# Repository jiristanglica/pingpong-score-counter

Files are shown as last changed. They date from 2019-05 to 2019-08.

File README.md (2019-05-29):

# Pingpong Score Counter

Pingpong score counter for our office pingis table.

## Architecture
Basic architecture consist of two Arduino Nano V3s that communicate wirelessly. There is a _buttons module_ and a _display module_. All parts are mounted in 3D printed enclosures. The .stl files for 3D printed parts are inside the `./assembly` folder in this repository.

### Buttons module
Buttons are mounted on each side of the table. Each button is connected into an Arduino Nano V3, which is mounted under the table.

**Components list**:
- 1x [Arduino Nano V3](https://store.arduino.cc/arduino-nano)
- 1x [NRF24L01+ module](https://www.elektroniikkaosat.com/c-45/p-464288850/NRF24L01-lahetin-vastaanotin.html)
- 1x [NRF24L01+ 5V adapter](https://www.elektroniikkaosat.com/c-45/p-529542940/NRF24L01-adapteri.html)
- 2x [Arcade Push Button](https://www.partco.fi/en/electromechanics/switches/arcade-switches/19574-kyt-arc33-sin.html)
- 2x 10kΩ resistor

Fritzing diagram showing the wiring:
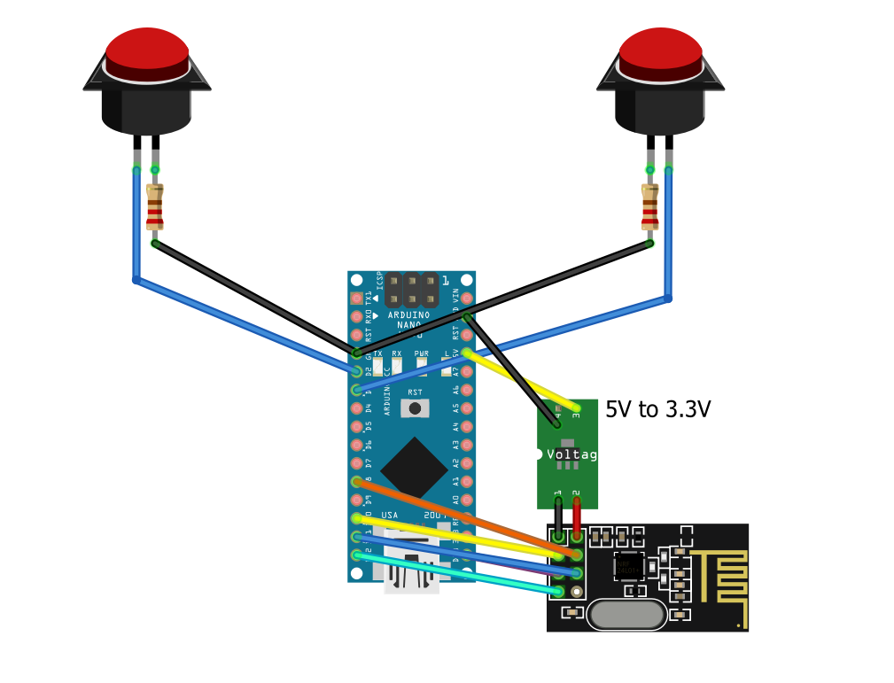
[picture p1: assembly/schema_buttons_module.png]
Buttons module schema


### Display module
Display is in a separate enclosure which can be placed on any suitable place within the reach of the 2.4GHz radio communication (and eyes of the players).

**Components list**:
- 1x [Arduino Nano V3](https://store.arduino.cc/arduino-nano)
- 1x [NRF24L01+ module](https://www.elektroniikkaosat.com/c-45/p-464288850/NRF24L01-lahetin-vastaanotin.html)
- 1x [NRF24L01+ 5V adapter](https://www.elektroniikkaosat.com/c-45/p-529542940/NRF24L01-adapteri.html)
- 1x [MAX7219 8x8x4 LED Matrix Module](https://www.partco.fi/en/arduino/arduino-playground/19683-max7219-mod-8x8x4.html)
- 1x [LK Buzzer](https://www.partco.fi/en/diy-kits/linkerkit/19405-lk-buzzer.html)

Fritzing diagram showing the wiring:
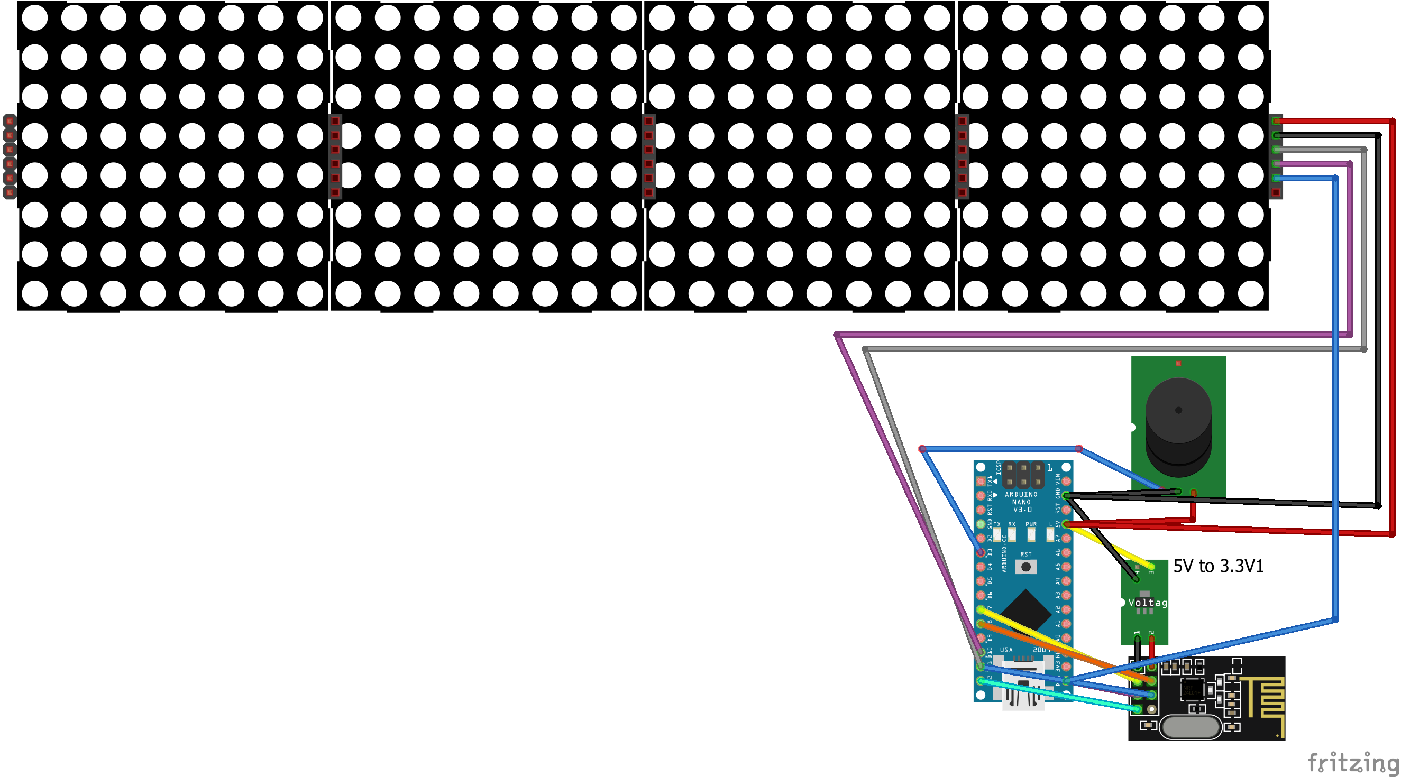
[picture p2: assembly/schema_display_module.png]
Buttons module schema


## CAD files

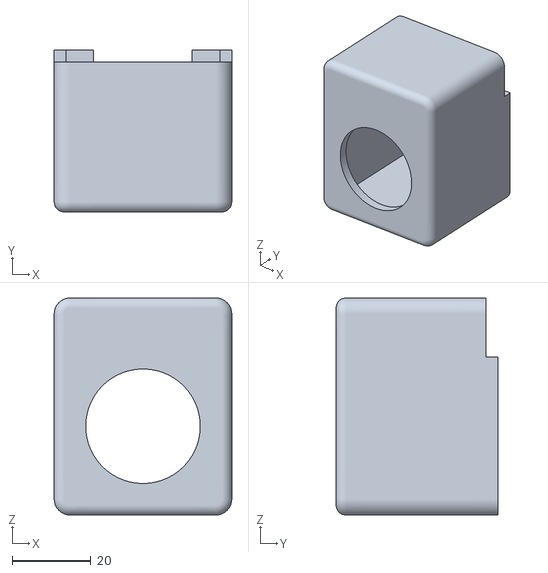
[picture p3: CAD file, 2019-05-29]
assembly/button_enclosure.stl
45.0 x 41.0 x 55.0

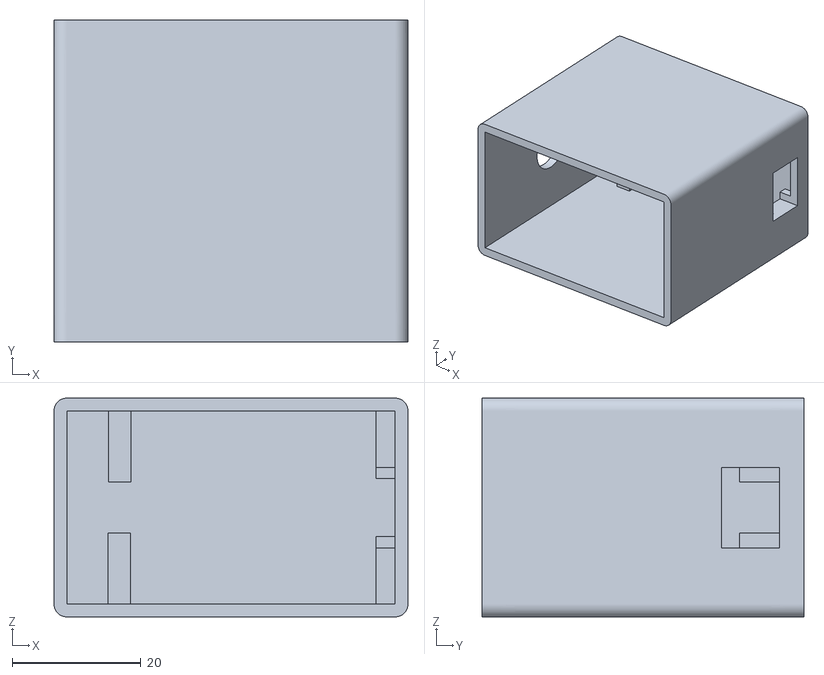
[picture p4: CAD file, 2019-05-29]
assembly/buttons_module_enclosure.stl
55.0 x 50.0 x 34.0

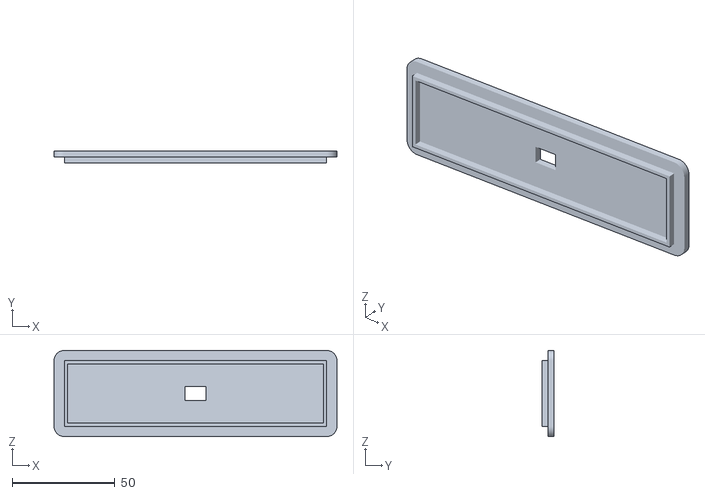
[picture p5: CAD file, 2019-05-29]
assembly/display_enclosure.stl
138.0 x 6.00 x 42.0

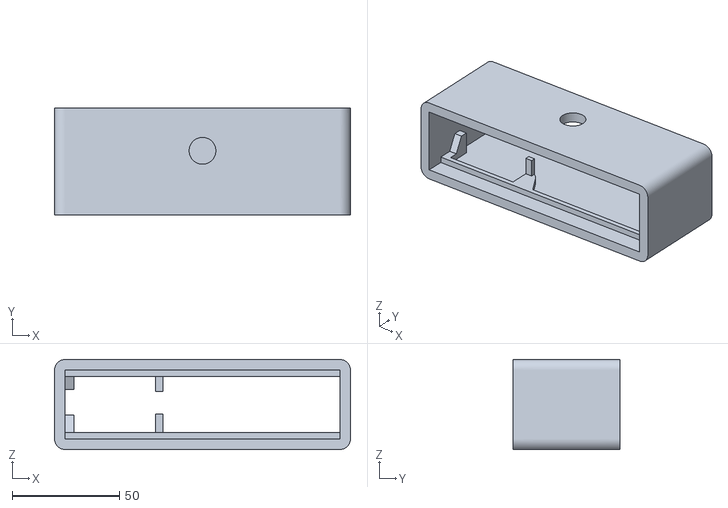
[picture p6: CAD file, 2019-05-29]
assembly/display_enclosure_lid.stl
138.0 x 50.0 x 42.0

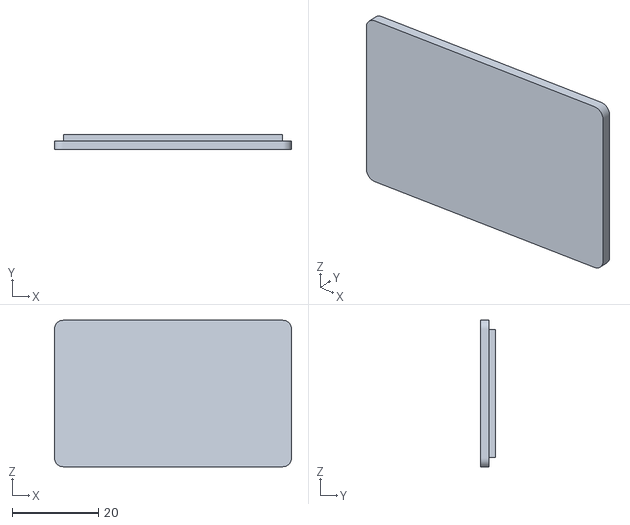
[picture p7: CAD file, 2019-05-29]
assembly/buttons_module_enclosure_lid.stl
55.0 x 3.50 x 34.0

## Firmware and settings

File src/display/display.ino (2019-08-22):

#include <nRF24L01.h>
#include <RF24.h>
#include <SPI.h>
#include "src/Display.h"
#include "src/Buzzer.h"

// Button 1 messages
#define RADIO_MSG_BUTTON_1_PRESS 0
#define RADIO_MSG_BUTTON_1_LONG_PRESS_1_SIGNAL 1
#define RADIO_MSG_BUTTON_1_LONG_PRESS_2_SIGNAL 2
#define RADIO_MSG_BUTTON_1_LONG_PRESS_1 3
#define RADIO_MSG_BUTTON_1_LONG_PRESS_2 4
// Button 2 messages
#define RADIO_MSG_BUTTON_2_PRESS 5
#define RADIO_MSG_BUTTON_2_LONG_PRESS_1_SIGNAL 6
#define RADIO_MSG_BUTTON_2_LONG_PRESS_2_SIGNAL 7
#define RADIO_MSG_BUTTON_2_LONG_PRESS_1 8
#define RADIO_MSG_BUTTON_2_LONG_PRESS_2 9

#define RADIO_MSG_HEARTBEAT 10

/** Buzzer variables */
Buzzer buzzer(3);

/** Radio varaibles */
RF24 radio(7, 8); // CE, CSN
const byte address[6] = "dsp001";
unsigned long lastHb = 0;
bool txLost = false;

/** Display variables */
Display disp = Display(4);

/** Display messages */
const char msgNewGame[] =    " New Game       ";  // 1
const char msgPlayer1Won[] = " Player 1 wins! ";  // 2
const char msgPlayer2Won[] = " Player 2 wins! ";  // 3
/** Display messages helper variables */
bool isTextScrolling = false;
unsigned long textScrollingTimer = 0;
byte msgDisplayed = 1;

/** Players variables */
typedef struct Players {
    int id;
    int score = 0;
    bool isServing = false;

    String scoreString() {
        char cstr[3]; // 2 chars + null termination
        itoa(this->score, cstr, 10);
        return cstr;
    }
    char scoreChar1() {
        String str = this->scoreString();
        if (str[1]) {
            return str[0];
        }
        return '0';
    }
    char scoreChar2() {
        String str = this->scoreString();
        if (str[1]) {
            return str[1];
        }
        return str[0];
    }
    void renderScore() {
        int renderOffset = 0;
        if (this->id == 2) {
            renderOffset = 19;
        }
        disp.printChar(this->scoreChar1(), renderOffset + 1);
        disp.printChar(this->scoreChar2(), renderOffset + 7);
        disp.setLed(7, renderOffset + 5, this->isServing);
        disp.setLed(7, renderOffset + 6, this->isServing);
        disp.setLed(7, renderOffset + 7, this->isServing);
    }
} Player;
Player player1;
Player player2;

/** Gameplay variables */
bool isGameOver = false;
int firstPlayerToPass = -1;

void setup()
{
    Serial.begin(57600);
    
    // Setup display
    disp.init();
    
    // Setup radio
    radio.begin();
    radio.openReadingPipe(0, address);
    radio.setPALevel(RF24_PA_MIN);
    radio.startListening();
    
    // Setup players
    player1.id = 1;
    player2.id = 2;

    playStartupTone();
    
    resetGame();
}

void loop()
{
    checkHeartbeat();
    if (radio.available()) {
        char text[3] = "";
        radio.read(&text, sizeof(text));
        handleRadioMessage(text);
    }
    if (isTextScrolling) {
        if (msgDisplayed == 1) {
            disp.scrollText(msgNewGame, 35);
        } else if (msgDisplayed == 2) {
            disp.scrollText(msgPlayer1Won, 35);
        } else if (msgDisplayed == 3) {
            disp.scrollText(msgPlayer2Won, 35);
        } else {
            resetScrollMessage();
        }
        if ((unsigned long)(millis() - textScrollingTimer) >= 6500) {
            resetScrollMessage();
        }
    }
}

/** Buzzer functions */
void signalLongPress1() {
    buzzer.beep(75);
    delay(50);
    buzzer.beep(75);  
}
void signalLongPress2() {
    buzzer.beep(100);
    delay(20);
    buzzer.beep(100);
    delay(20);
    buzzer.beep(100);
    delay(20);
    buzzer.beep(100);
}
void playStartupTone() {
    int length = 5;
    char notes[] = "eee C";
    int beats[] = { 2, 2, 2, 2, 5 }; 
    int tempo = 60;

    buzzer.playMusic(notes, beats, tempo, length);

    delay(200);
}
void playWinTone() {
    int length = 12;
    char notes[] = "cdefgabC eb";
    int beats[] = { 2, 2, 2, 2, 2, 2, 2, 2, 1, 2, 6 }; 
    int tempo = 60;

    buzzer.playMusic(notes, beats, tempo, length);
}

/** Radio handler */
void handleRadioMessage(char msgChars[]) {
    msgChars[2] = '\0'; // failing atoi is undefined behaviour.. trying to avoid.. TODO: is strtol possible ?
    // COMMENT: using string commands would be a bit more robust solution. fex: "1" instead of 1
    // If using integer commands, I would convert this to switch-case
    int msgId = atoi(msgChars);

    if (msgId == RADIO_MSG_HEARTBEAT) {
        handleHeartbeat();
    } else {
        // Any button event cancel scrolling text
        if (isTextScrolling) {
            resetScrollMessage();
            return;
        }
        
        if (msgId == RADIO_MSG_BUTTON_1_PRESS) addPlayerScore(1);
        if (msgId == RADIO_MSG_BUTTON_1_LONG_PRESS_1_SIGNAL) signalLongPress1();
        if (msgId == RADIO_MSG_BUTTON_1_LONG_PRESS_2_SIGNAL) signalLongPress2();
        if (msgId == RADIO_MSG_BUTTON_1_LONG_PRESS_1) removePlayerScore(1);
        if (msgId == RADIO_MSG_BUTTON_1_LONG_PRESS_2) resetGame();
    
        if (msgId == RADIO_MSG_BUTTON_2_PRESS) addPlayerScore(2);
        if (msgId == RADIO_MSG_BUTTON_2_LONG_PRESS_1_SIGNAL) signalLongPress1();
        if (msgId == RADIO_MSG_BUTTON_2_LONG_PRESS_2_SIGNAL) signalLongPress2();
        if (msgId == RADIO_MSG_BUTTON_2_LONG_PRESS_1) removePlayerScore(2);
        if (msgId == RADIO_MSG_BUTTON_2_LONG_PRESS_2) resetGame();
    }
}

void handleHeartbeat() {
    lastHb = millis();
    if (txLost == true) {
        txLost = false;
        disp.clear();
        displayPlayerScores();
    }
}
void checkHeartbeat() {
    if (txLost == false && millis() - lastHb > 11000) {
        txLost = true;
        disp.printText("NO TX");
    }
}

/** Display functions */
void displayScrollMessage(byte msgId) {
    msgDisplayed = msgId;
    isTextScrolling = true;
    textScrollingTimer = millis();
}
void resetScrollMessage() {
    isTextScrolling = false;
    disp.clear();
    disp.resetScrollPosition();
    displayPlayerScores();
}
void displayPlayerScores() {
    // Score delimiter
    disp.setLed(2, 15, 1);
    disp.setLed(2, 16, 1);
    disp.setLed(5, 15, 1);
    disp.setLed(5, 16, 1);

    // Score numbers
    player1.renderScore();
    player2.renderScore();
}


/** Players logic */
void addPlayerScore(int playerId) {
    // If game has ended, use a short press as a shortcut to reset the game
    if (isGameOver) {
        resetGame();
        return;
    }

    buzzer.beep(100);
    if (player1.score == 0 && !player1.isServing && player2.score == 0 && !player2.isServing) {
        // New game, first point determines who is serving first
        if (playerId == 1) {
            player1.isServing = true;
            firstPlayerToPass = 1;
            player1.renderScore();
        }
        if (playerId == 2) {
            player2.isServing = true;
            firstPlayerToPass = 2;
            player2.renderScore();
        }
        sendScoreMessage();
        return;
    }
    if (playerId == 1) {
        player1.score++;
    }
    if (playerId == 2) {
        player2.score++;
    }
    checkServing();
    displayPlayerScores();
    sendScoreMessage();
    checkWin();
}
void removePlayerScore(int playerId) {
    if (playerId == 1 && player1.score > 0) {
        player1.score--;
        checkServing();
    }
    if (playerId == 2 && player2.score > 0) {
        player2.score--;
        checkServing();
    }
    displayPlayerScores();
    sendScoreMessage();
}

int getPassingPlayer(int score1, int score2, int firstPasser)
{
    int fp = firstPasser - 1;
    int currentPasser = 0;
    int totalscore = score1 + score2;
    if (totalscore >= 20) {
        currentPasser = (int)(totalscore + fp) % 2;
    }
    else {
        currentPasser = (int)(totalscore / 2 + fp) % 2;
    }

    return currentPasser + 1;
}

void checkServing() {
    int passingPlayer = getPassingPlayer(player1.score, player2.score, firstPlayerToPass);
    player1.isServing = passingPlayer == 1;
    player2.isServing = passingPlayer == 2;
}
void checkWin() {
    if (player1.score >= 11 || player2.score >= 11) {
        if ((player1.score - player2.score) >= 2) {
            isGameOver = true;
            delay(1000);
            // displayScrollMessage(2);
            playWinTone();
        }
        if ((player2.score - player1.score) >= 2) {
            isGameOver = true;
            delay(1000);
            // displayScrollMessage(3);
            playWinTone();
        }
    }  
}
void resetGame() {
    isGameOver = false;
    player1.score = 0;
    player1.isServing = false;
    player2.score = 0;
    player2.isServing = false;
    displayPlayerScores();
    displayScrollMessage(1);
    buzzer.beep(500);
    sendNewgameMessage();
}

/** Integration logic */
void sendScoreMessage() {
    int servingPlayer = 0;
    if (player1.isServing) servingPlayer = 1;
    if (player2.isServing) servingPlayer = 2;

    Serial.print("score_");
    Serial.print(player1.score);
    Serial.print("_");
    Serial.print(player2.score);
    Serial.print("_");
    Serial.print(servingPlayer);
}
void sendNewgameMessage() {
    Serial.print("newgame");
}

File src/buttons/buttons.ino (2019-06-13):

#include <SPI.h>
#include <nRF24L01.h>
#include <RF24.h>
#include "src/Button.h"

// Button 1 messages
#define RADIO_MSG_BUTTON_1_PRESS 0
#define RADIO_MSG_BUTTON_1_LONG_PRESS_1_SIGNAL 1
#define RADIO_MSG_BUTTON_1_LONG_PRESS_2_SIGNAL 2
#define RADIO_MSG_BUTTON_1_LONG_PRESS_1 3
#define RADIO_MSG_BUTTON_1_LONG_PRESS_2 4
// Button 2 messages
#define RADIO_MSG_BUTTON_2_PRESS 5
#define RADIO_MSG_BUTTON_2_LONG_PRESS_1_SIGNAL 6
#define RADIO_MSG_BUTTON_2_LONG_PRESS_2_SIGNAL 7
#define RADIO_MSG_BUTTON_2_LONG_PRESS_1 8
#define RADIO_MSG_BUTTON_2_LONG_PRESS_2 9

#define RADIO_MSG_HEARTBEAT 10

/** Radio variables */
RF24 radio(10, 8); // CE, CSN
const byte address[6] = "dsp001";
unsigned long lastHb = 0;

/** Buttons variables */
Button button1 = Button(1, 2);
Button button2 = Button(2, 3);

void setup() {
    Serial.begin(9600);
    Serial.print("Ready");
    Serial.println();
    
    // Setup radio
    radio.begin();
    radio.openWritingPipe(address);
    radio.setPALevel(RF24_PA_MIN);
    radio.stopListening();

    // Setup buttons
    pinMode(button1.pin, INPUT_PULLUP);
    pinMode(button2.pin, INPUT_PULLUP);

    button1.setShortPressCallback(onButtonShortPress);
    button1.setLongPress_1Callback(onButtonLongPress_1);
    button1.setLongPress_2Callback(onButtonLongPress_2);
    button1.setLongPress_1SignalCallback(onButtonLongPress_1_Signal);
    button1.setLongPress_2SignalCallback(onButtonLongPress_2_Signal);

    button2.setShortPressCallback(onButtonShortPress);
    button2.setLongPress_1Callback(onButtonLongPress_1);
    button2.setLongPress_2Callback(onButtonLongPress_2);
    button2.setLongPress_1SignalCallback(onButtonLongPress_1_Signal);
    button2.setLongPress_2SignalCallback(onButtonLongPress_2_Signal);
}

void loop() {
    button1.checkState();
    button2.checkState();
    sendHeartbeat();
}

/** Radio handler */
void sendRadioMessage(int msgId) {
    if(msgId > 0xff) return; 
    
    char buff[2]; // one byte of data max.. and null termination
    itoa(msgId, (char*)&buff, 10);
    radio.write(&buff, sizeof(buff));
}

void sendHeartbeat() {
    if (millis() - lastHb > 5000) {
        sendRadioMessage(RADIO_MSG_HEARTBEAT);
        lastHb = millis();
    }
}

/** Button handlers */
void onButtonShortPress(int id) {
    if (id == 1) sendRadioMessage(RADIO_MSG_BUTTON_1_PRESS);
    if (id == 2) sendRadioMessage(RADIO_MSG_BUTTON_2_PRESS);
}
void onButtonLongPress_1(int id) {
    if (id == 1) sendRadioMessage(RADIO_MSG_BUTTON_1_LONG_PRESS_1);
    if (id == 2) sendRadioMessage(RADIO_MSG_BUTTON_2_LONG_PRESS_1);
}
void onButtonLongPress_2(int id) {
    if (id == 1) sendRadioMessage(RADIO_MSG_BUTTON_1_LONG_PRESS_2);
    if (id == 2) sendRadioMessage(RADIO_MSG_BUTTON_2_LONG_PRESS_2);
}
void onButtonLongPress_1_Signal(int id) {
    if (id == 1) sendRadioMessage(RADIO_MSG_BUTTON_1_LONG_PRESS_1_SIGNAL);
    if (id == 2) sendRadioMessage(RADIO_MSG_BUTTON_2_LONG_PRESS_1_SIGNAL);
}
void onButtonLongPress_2_Signal(int id) {
    if (id == 1) sendRadioMessage(RADIO_MSG_BUTTON_1_LONG_PRESS_2_SIGNAL);
    if (id == 2) sendRadioMessage(RADIO_MSG_BUTTON_2_LONG_PRESS_2_SIGNAL);
}

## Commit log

2019-05-29 Expand readme file Change file structure
    [button_enclosure.stl, buttons_module_enclosure.stl, buttons_module_enclosure_lid.stl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]
2019-05-29 Remove debug serial printing
2019-06-13 small improvements to button logic and some sanitychecks (#1)
    * Refactored button press logic, got rid of the delay debounce command
    * Couple sanitychecks
    * Fix long press logic
    * Fix incoming message max length
    [Button.cpp, Button.h, buttons.ino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]
2019-06-13 Allow to skip through scrolling message Fix serving indicator after the score is 10:10
    [display.ino]
2019-08-06 logic to determine who is serving / passing. refactored to points based.. (#2)
    Fix serving indicator to be score based
    [display.ino]
2019-08-06 Fix bugs
    Correctly assign initially serving player
    Fix serving inidicator after score was 10:10
    [display.ino]
